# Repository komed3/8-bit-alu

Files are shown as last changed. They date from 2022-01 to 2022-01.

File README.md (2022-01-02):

# 8-bit arithmetic logic unit

Project to build an 8-bit arithmetic logic unit (ALU) consisting only of transistors. Further on, the construction of a transistor processor based on this ALU will follow.

## Description

The arithmetic-logic unit is a part of a CPU. This project is about building a controllable arithmetic unit with a 8-bit processing span (hex. ``00-FF``, dec. ``0-255``).

The ALU is built entirely from discrete transistors, resistors, diodes and LEDs. No integrated circuits are used. In its finished state, it will contain functions defined below and will be controlled by a CPU (also made of transistors) in the future.

The aim is to illustrate how computers calculate up to the execution of elementary programmes.

## Input

The inputs of the arithmetic-logic unit are the two 8-bit wide data words ``A`` and ``B``, and 8 control lines:

+ ``~A`` inverts word ``A``
+ ``~B`` inverts word ``B``
+ ``~C`` inhibit carry
+ ``~AND`` inhibit AND
+ ``Cin`` carry input (INC/SUB)
+ ``~X`` inverts output ``X``
+ ``RS`` logical right shift
+ ``LS`` logical left shift

## Functions

The arithmetic-logic unit includes the following instructions, which are defined in the coding table below with their respective control lines:

### Arithmetic

+ addition (ADD)
+ subtraction (SUB)
+ increment (INC)
+ comparison (CMP)

### Logic

+ negation (NOT)
+ conjunction (AND + NAND)
+ disjunction (OR + NOR)
+ contravalence (XOR + XNOR)
+ right and left shift (LSR/LSL)

### Coding table

| LS | RS | ~X | Cin | ~AND | ~C | ~B | ~A | FNC |
|:--:|:--:|:--:|:---:|:----:|:--:|:--:|:--:|:-----:|
| 0  | 0  | 0  | 0 | 0 | 0  | 0  | 0  | ADD |
| 0  | 0  | 0  | 0 | 0 | 0  | 0  | 1  | NOT A |
| 0  | 0  | 0  | 0 | 0 | 0  | 1  | 0  | NOT B |
| 0  | 0  | 0  | 0 | 0 | 1  | 0  | 0  | XOR |
| 0  | 0  | 0  | 0 | 1 | 0  | 0  | 0  | OR |
| 0  | 0  | 0  | 0 | 1 | 0  | 1  | 1  | NAND  |
| 0  | 0  | 0  | 1 | 0 | 0  | 0  | 0  | INC |
| 0  | 0  | 0  | 1 | 0 | 0  | 1  | 0  | SUB |
| 0  | 0  | 1  | 0 | 0 | 0  | 0  | 0  | NOT X |
| 0  | 0  | 1  | 0 | 0 | 1  | 0  | 0  | XNOR  |
| 0  | 0  | 1  | 0 | 1 | 0  | 0  | 0  | NOR |
| 0  | 0  | 1  | 0 | 1 | 0  | 1  | 1  | AND |
| 0  | 1  | 0  | 0 | 0 | 0  | 0  | 0  | LSR |
| 1  | 0  | 0  | 0 | 0 | 0  | 0  | 0  | LSL |

## Output

The output of the arithmetic-logic unit is the 8-bit wide data word ``X`` and the status register consisting of another 8 bits.

### Status register

| Flag | Name | Description |
|:----:|---|---|
| C | Carry | Enables numbers larger than a single word to be added/subtracted by carrying a binary digit from a less significant word to the least significant bit of a more significant word as needed. |
| V | Overflow | Indicates that the signed result of an operation is too large to fit in the register width using two's complement representation. |
| S | Sign | Indicates that the result of a mathematical operation is negative. |
| Z | Zero | Indicates that the result of an arithmetic or logical operation (or a load) was zero. |
| P | Parity | Indicates whether the number of set bits of the last result is even or odd (``Odd=1``). |
| H | Half-carry | Indicates that a bit carry was produced between the nibbles (4-bit halves of a byte operand) as a result of the last arithmetic operation. |

### Magnitude comparator

Part of the ALU is the _magnitude comparator_. It is unaffected by arithmetic (or even shift) operations. It compares the input words ``A`` and ``B`` for equality and has two outputs that are included in the status register:

+ ``A=B`` Indicates when the entered words ``A`` and ``B`` are equal.
+ ``A>B`` Indicates when the entered word ``A`` is greather than ``B``.

If both outputs of the status register are ``0``, then ``A<B`` applies. No separate data wire is provided for this.

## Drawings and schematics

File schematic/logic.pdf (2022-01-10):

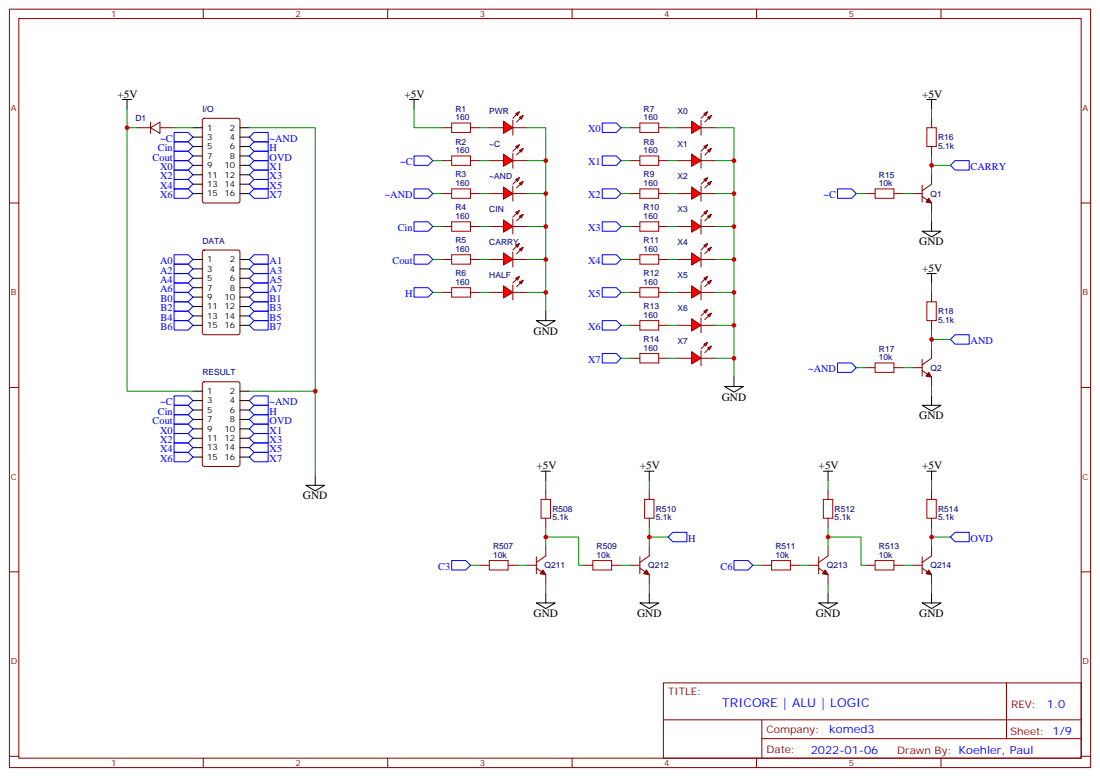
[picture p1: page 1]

Drawn By: Koehler, Paul

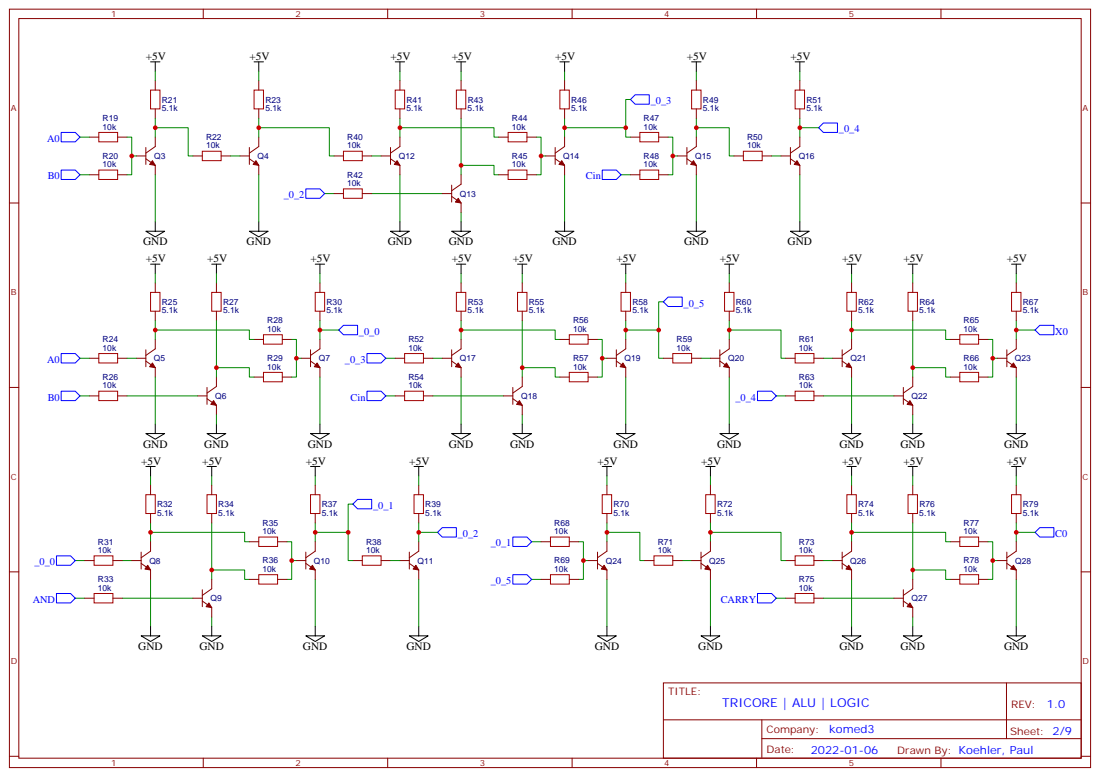
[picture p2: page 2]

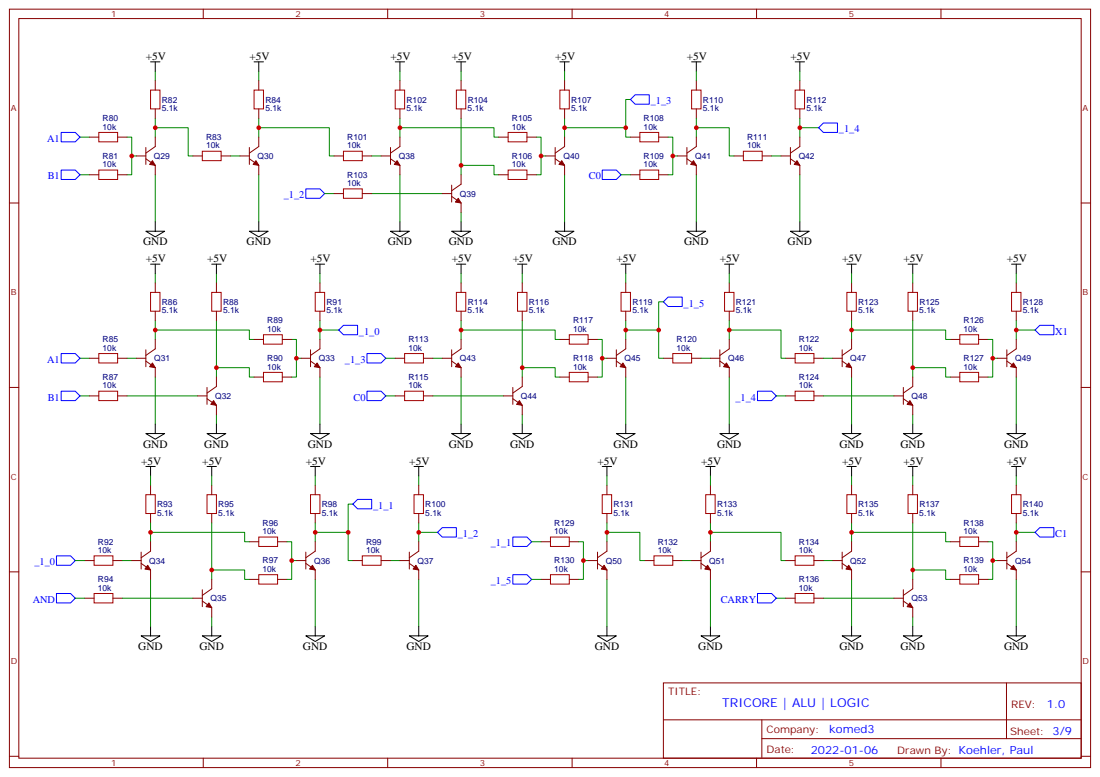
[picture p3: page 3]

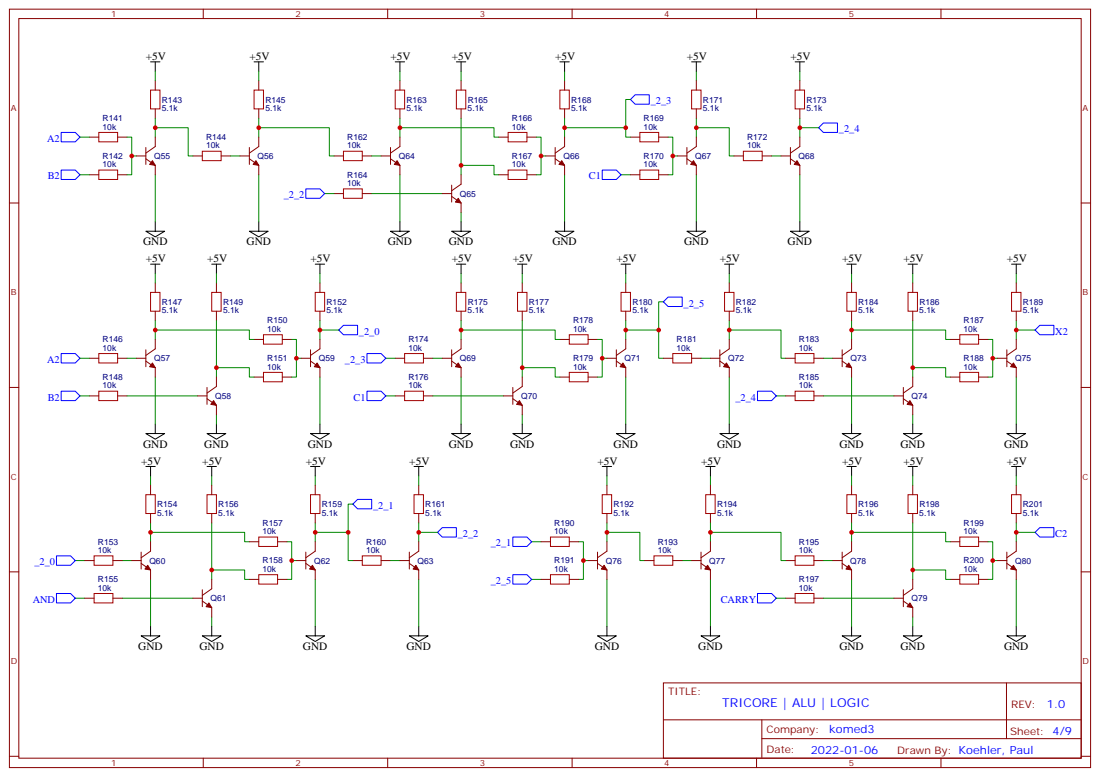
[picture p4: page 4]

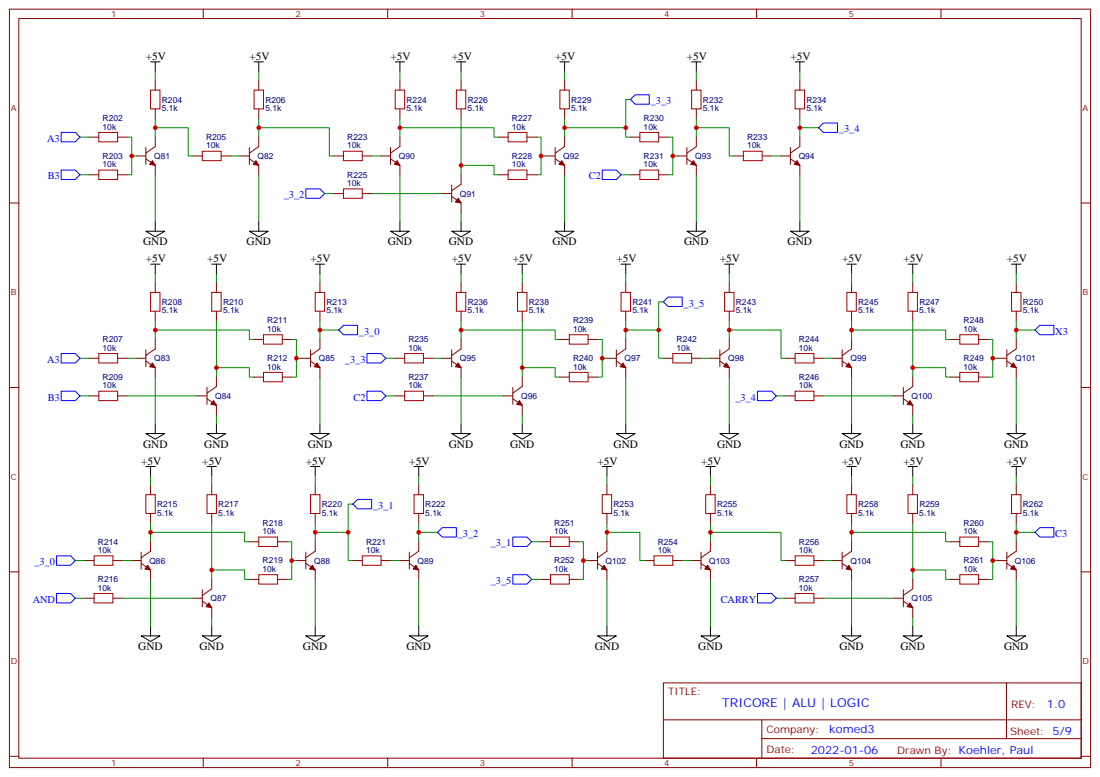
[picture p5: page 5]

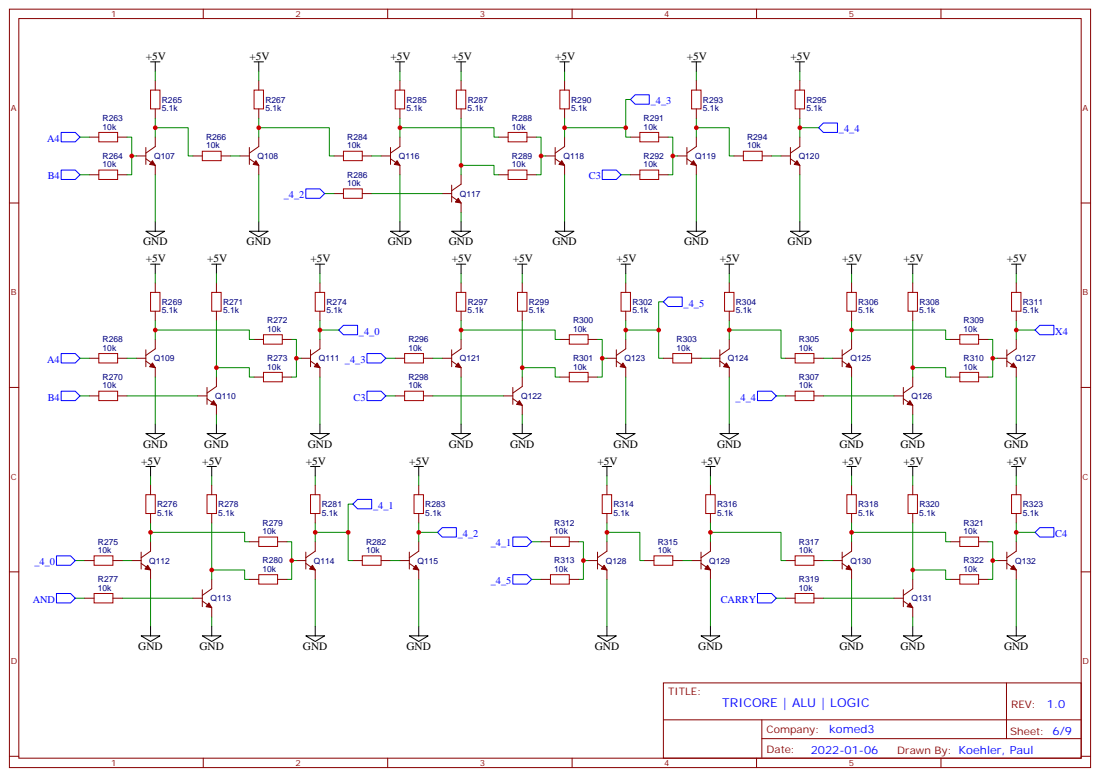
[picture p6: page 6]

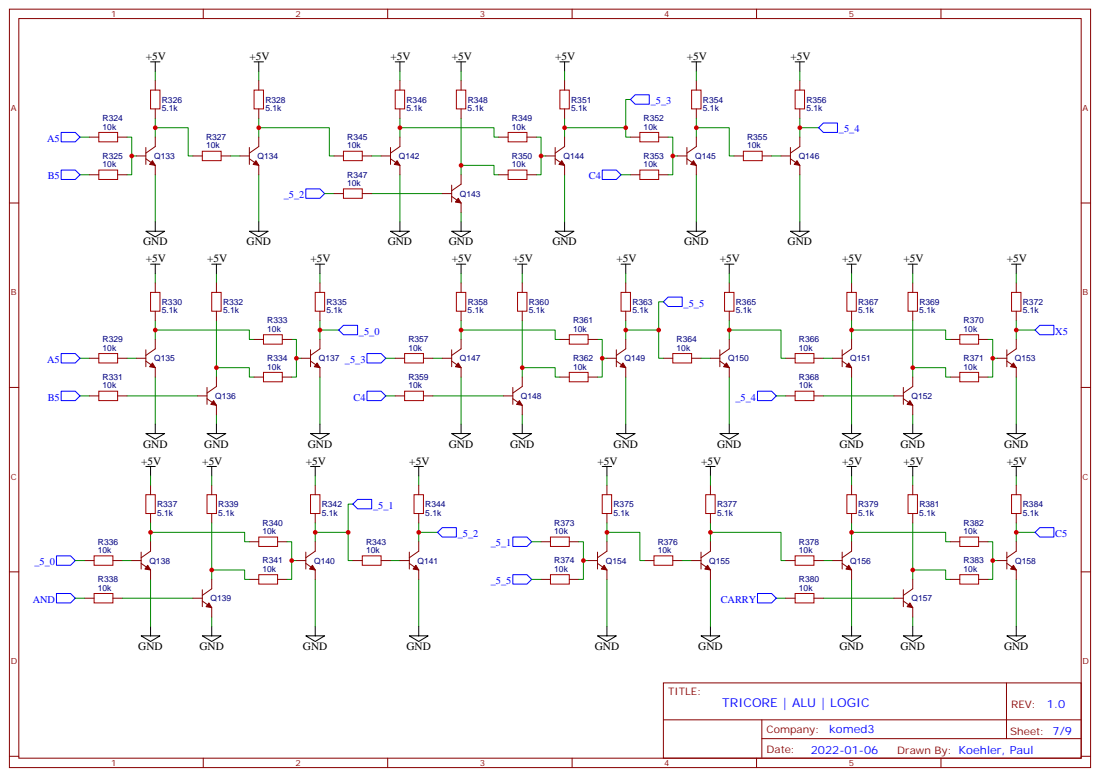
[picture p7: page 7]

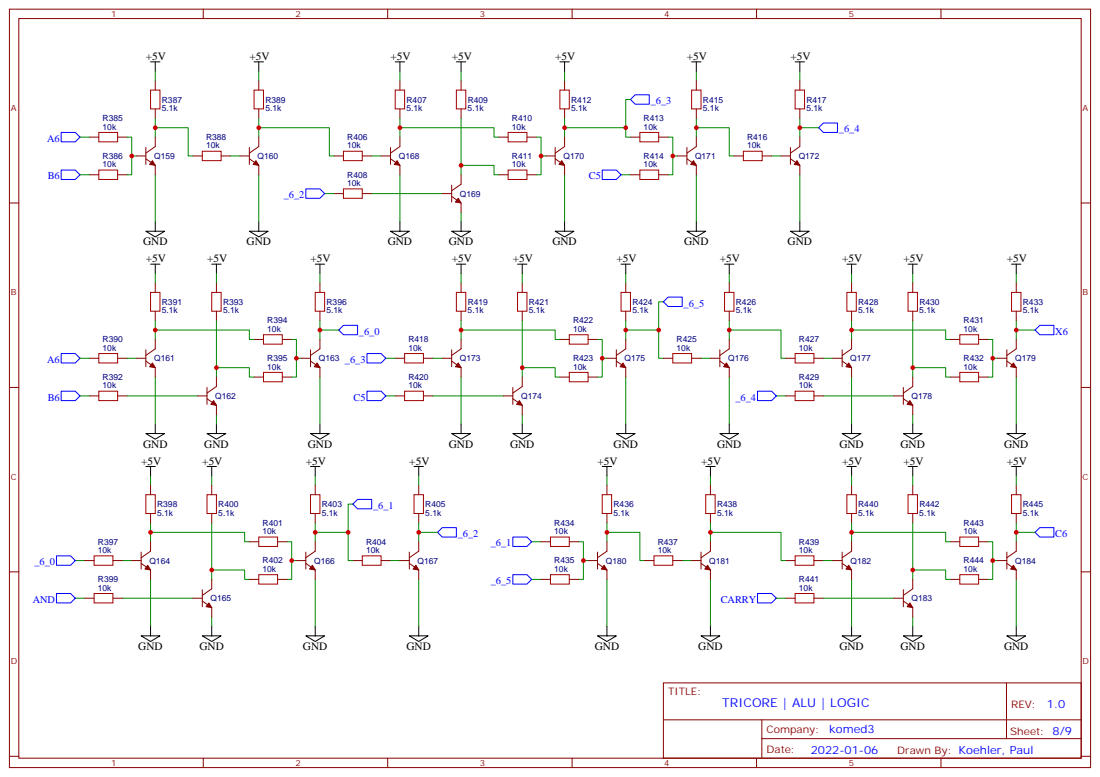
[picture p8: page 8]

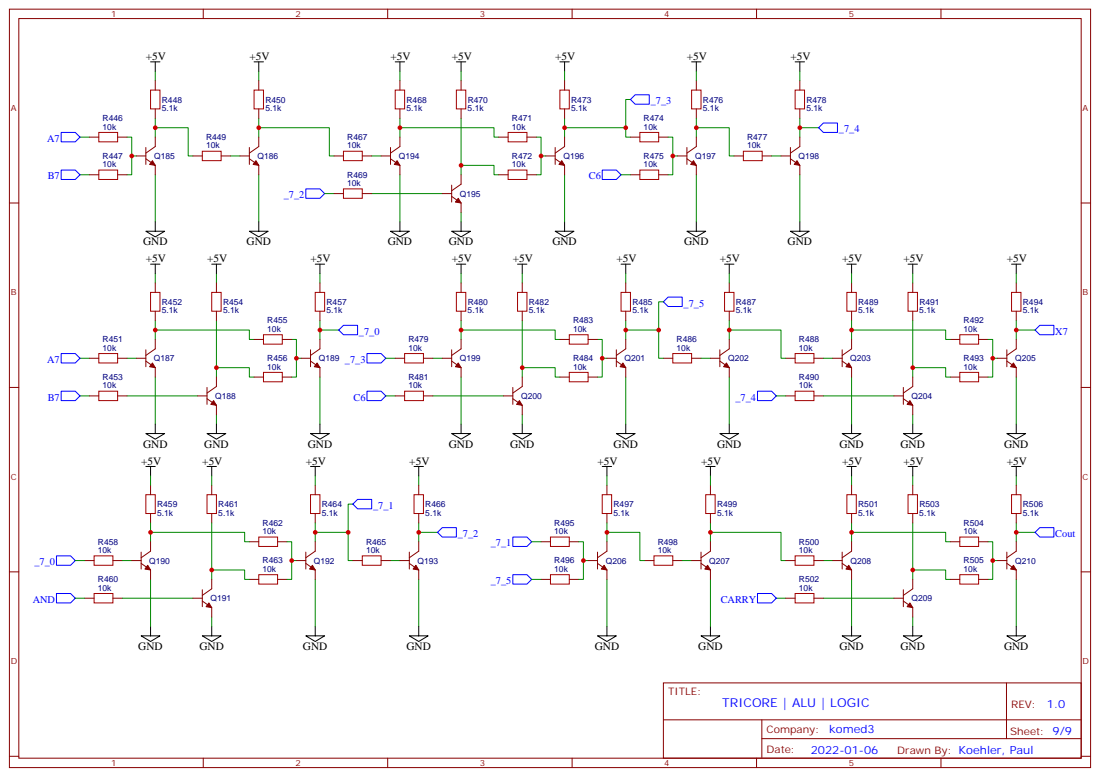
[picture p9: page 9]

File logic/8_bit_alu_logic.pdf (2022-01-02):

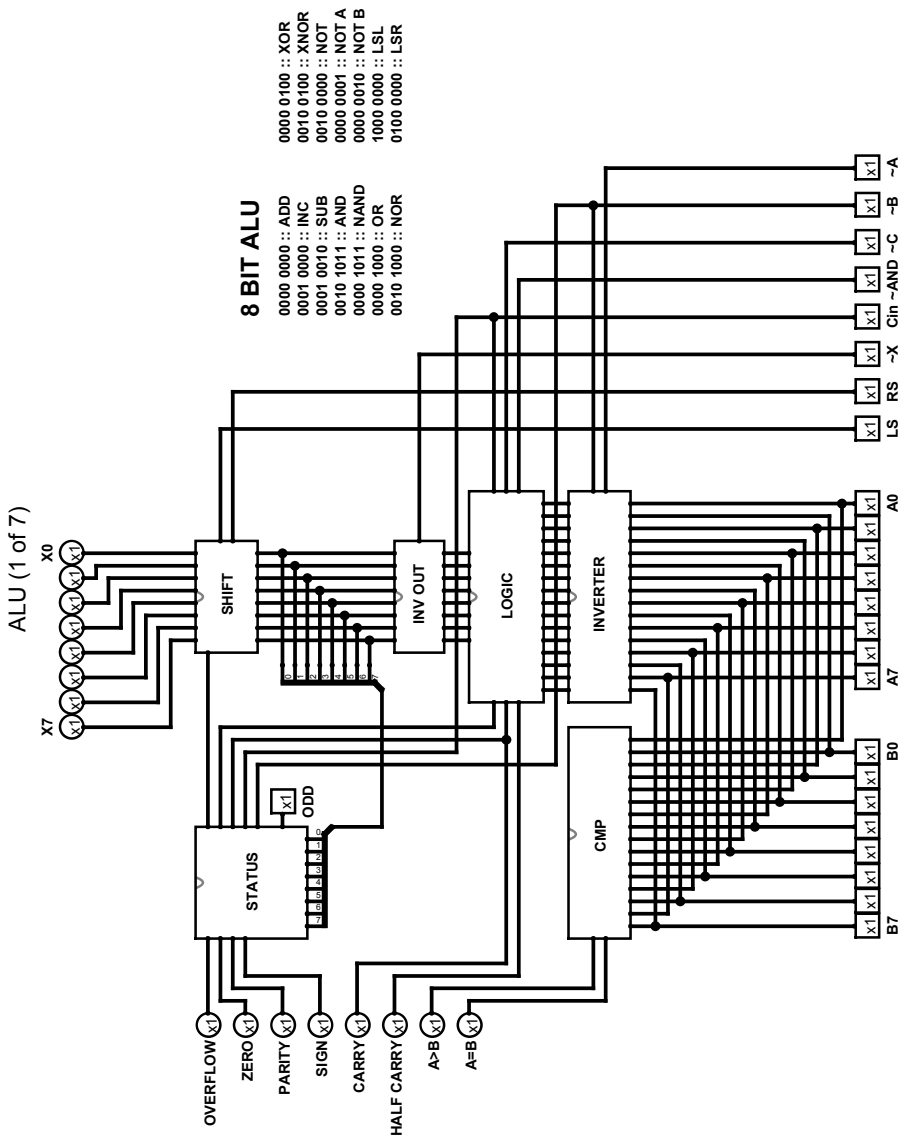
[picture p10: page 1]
ALU (1 of 7); 0000 0001 :: NOT A; PARITY x1 0000 0000 :: ADD; SHIFT; 1000 0000 :: LSL; 0010 1011 :: AND; Cin; 0001 0010 :: SUB; SIGN x1; 0000 0100 :: XOR; STATUS ZERO x1; LOGIC; 0100 0000 :: LSR; ~AND; ODD; 8 BIT ALU; 0010 0000 :: NOT; CMP; OVERFLOW x1; INV OUT; 0000 1011 :: NAND; HALF CARRY x1; INVERTER; CARRY x1; 0010 1000 :: NOR; 0001 0000 :: INC; 0010 0100 :: XNOR; 0000 0010 :: NOT B

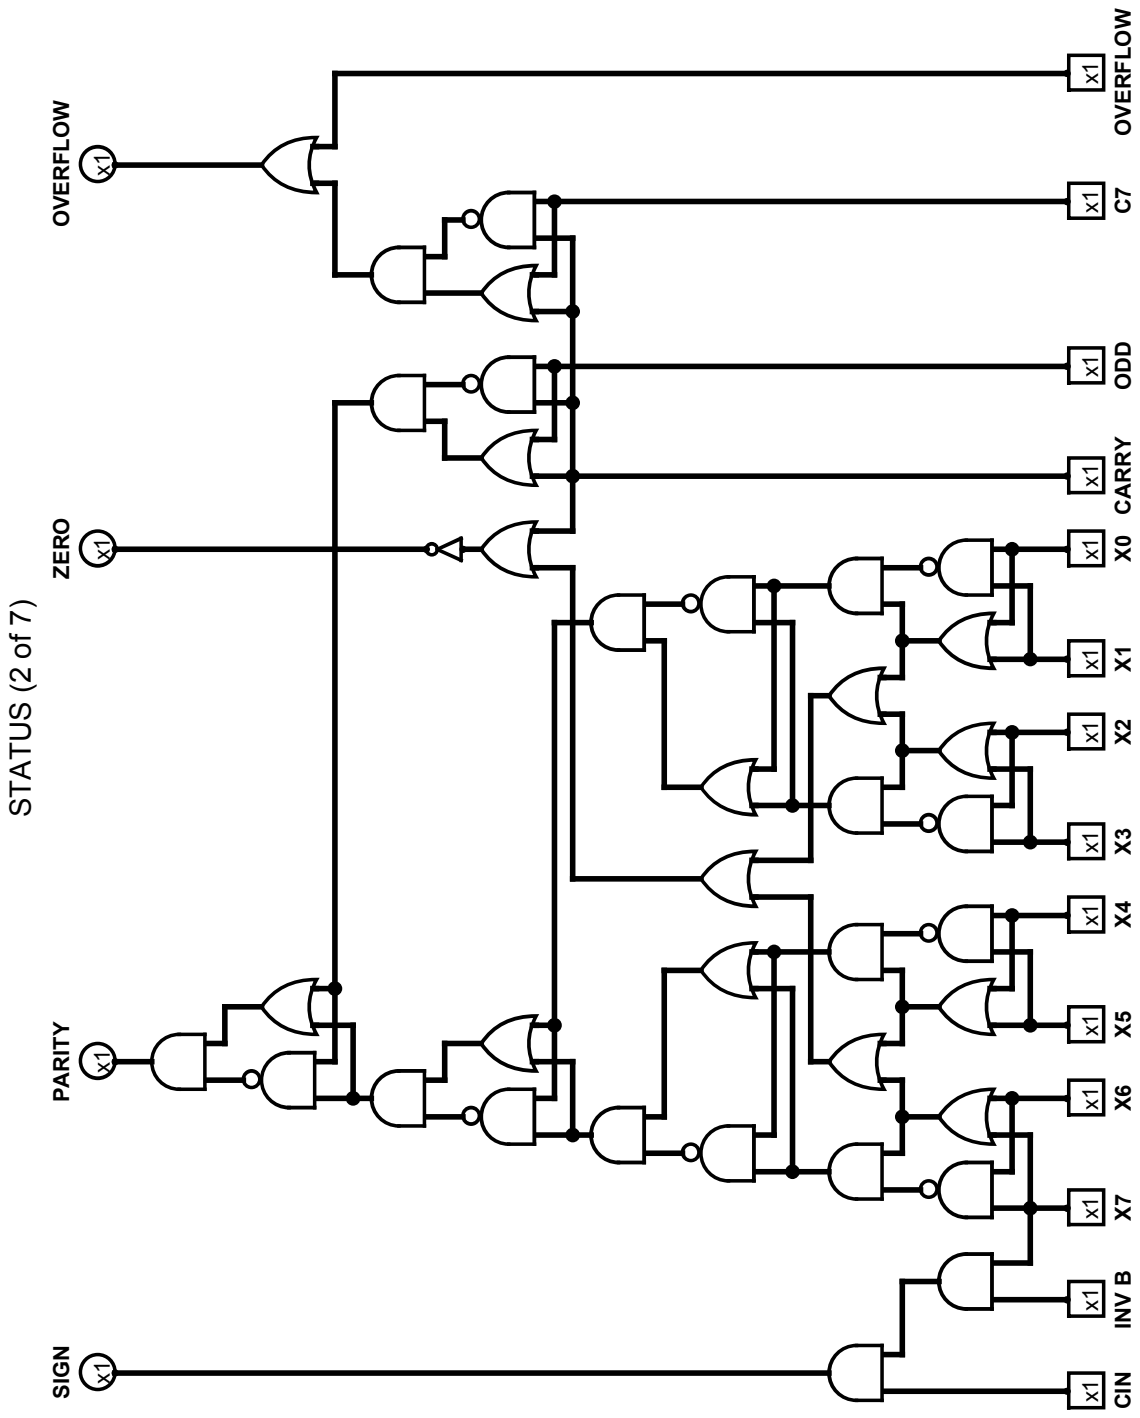
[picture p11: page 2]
STATUS (2 of 7); CIN; X0 ODD; PARITY; C7 CARRY; OVERFLOW; X6 INV B; ZERO; SIGN; X5 OVERFLOW

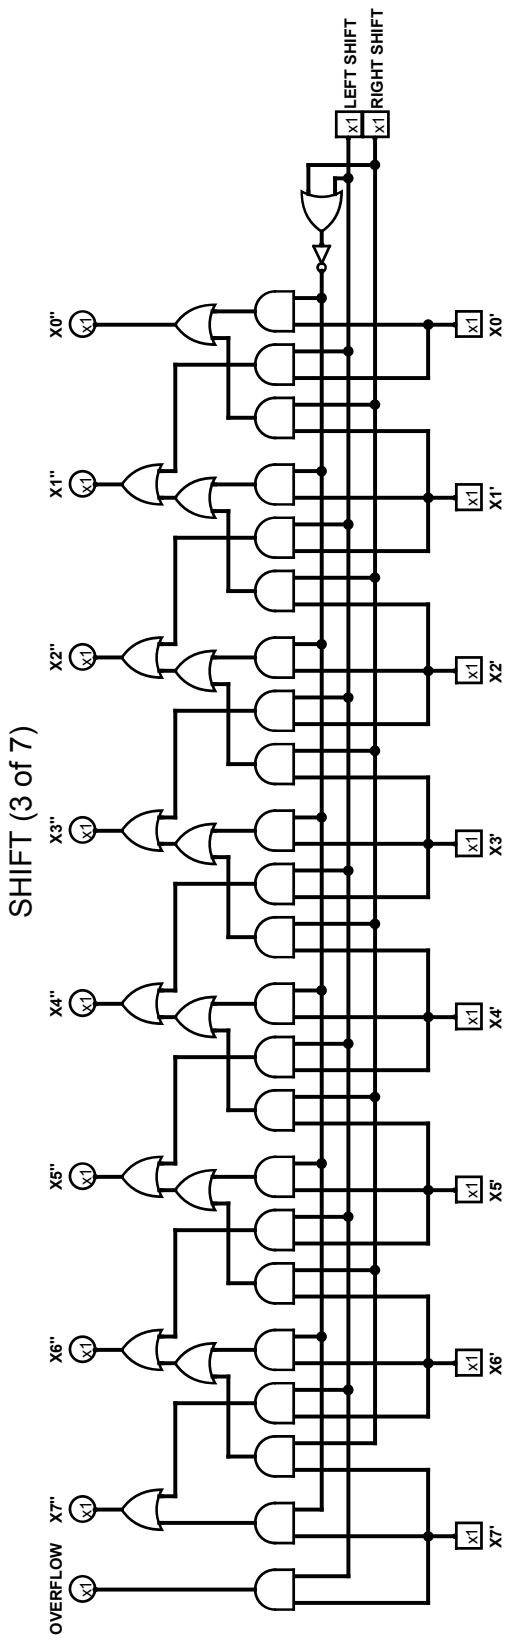
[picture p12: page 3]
SHIFT (3 of 7); OVERFLOW; LEFT SHIFT x1; RIGHT SHIFT x1

INV X x1

INV OUT (4 of 7)

LOGIC (5 of 7); HALF CARRY x1; INHIBIT CARRY x1; INHIBIT AND x1; CARRY OUT x1; CARRY IN x1

INV A/B (6 of 7); INV A x1; INV B x1

CMP (7 of 7)

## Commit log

2021-12-23 wire output + flags
2021-12-26 cmp circuit
2021-12-26 finish cmp circuit
2021-12-26 circuit appearance
2021-12-26 wire first 4 bits
2021-12-26 wire bits 5...8
2021-12-26 update wireing
2021-12-26 finish wireing
2021-12-26 add alu circuit appearance
2021-12-27 simplify wireing for ALU
2021-12-29 add pcb + sheets
2021-12-29 add gerber files
    [Gerber_BoardOutline.GKO, Gerber_BottomLayer.GBL, Gerber_BottomSolderMaskLayer.GBS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]
2021-12-30 fix gerber (1 bit logic)
    [Gerber_BoardOutline.GKO, Gerber_BottomLayer.GBL, Gerber_BottomSolderMaskLayer.GBS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]
2021-12-30 add gerber files for Q XOR M
    [Gerber_BoardOutline.GKO, Gerber_BottomLayer.GBL, Gerber_BottomSolderMaskLayer.GBS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]
2021-12-31 restart project
    [Gerber_BoardOutline.GKO, Gerber_BottomLayer.GBL, Gerber_BottomSolderMaskLayer.GBS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]
2022-01-01 add sub circuits
2022-01-01 add ALU logic circuit
2022-01-01 add status register circuit
2022-01-03 update circuits
2022-01-05 add circuits for CMP
2022-01-06 add logic circuits for BIT 4..7
2022-01-06 add schematics for logic
2022-01-09 create DSN file
    [Autorouter_PCB_TRICORE_ALU_LOGIC.dsn, Autorouter_PCB_TRICORE_ALU_LOGIC_NO_GND.dsn]
2022-01-10 update DSN file
    [Autorouter_PCB_TRICORE_ALU_LOGIC.dsn, Autorouter_PCB_TRICORE_ALU_LOGIC_NO_GND.dsn]
2022-01-10 change resistors for LEDs
2022-01-10 update gerber files
    [Gerber_BoardOutline.GKO, Gerber_BottomLayer.GBL, Gerber_BottomSolderMaskLayer.GBS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]
